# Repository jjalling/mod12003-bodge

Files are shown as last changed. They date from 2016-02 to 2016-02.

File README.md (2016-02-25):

MOD12003 bodge board
====================

During testing, the linear driver on the MOD12003 was shown not to be robust
enough; it lost bias during an abusive "file" test (rapidly shorting/opening
the output by rubbing a wire over a file). This is an updated driver circuit
to be patched into Rev A of MOD12003.

This repository uses submodules. Download with `git clone --recursive`.

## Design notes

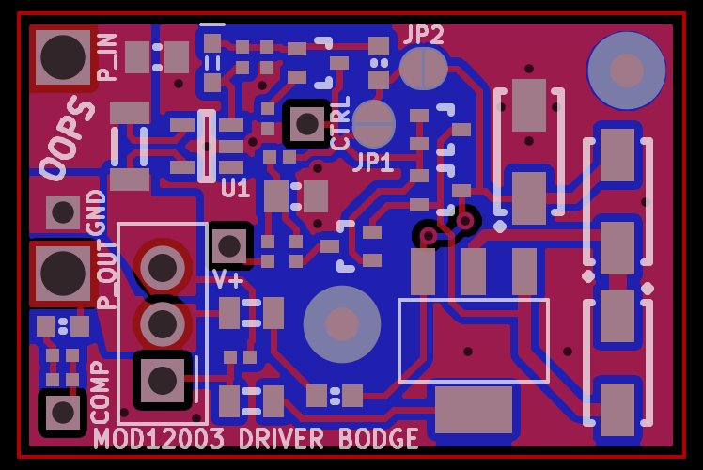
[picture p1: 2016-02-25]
renders/Overview.png

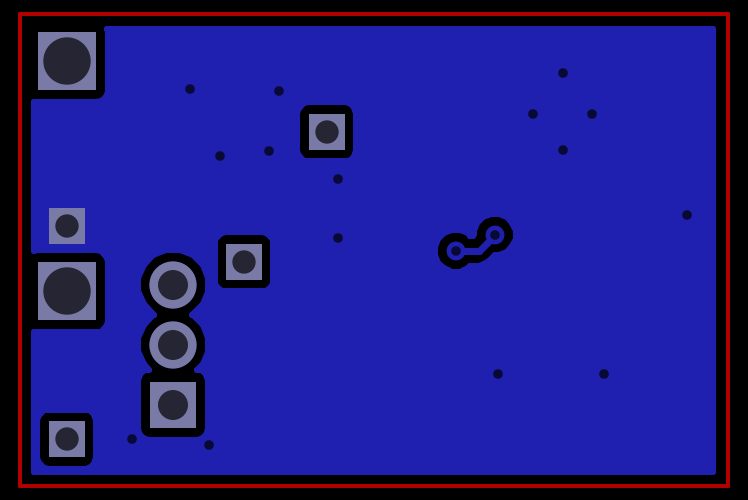
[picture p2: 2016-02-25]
renders/B_Cu.png

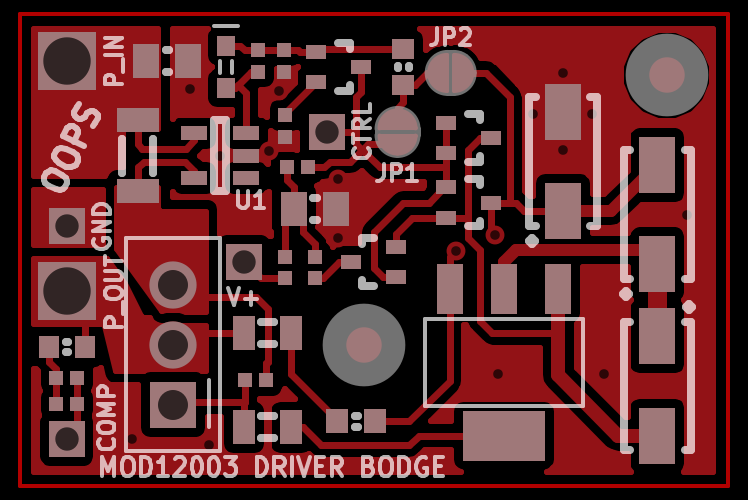
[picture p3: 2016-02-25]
renders/F_Cu.png

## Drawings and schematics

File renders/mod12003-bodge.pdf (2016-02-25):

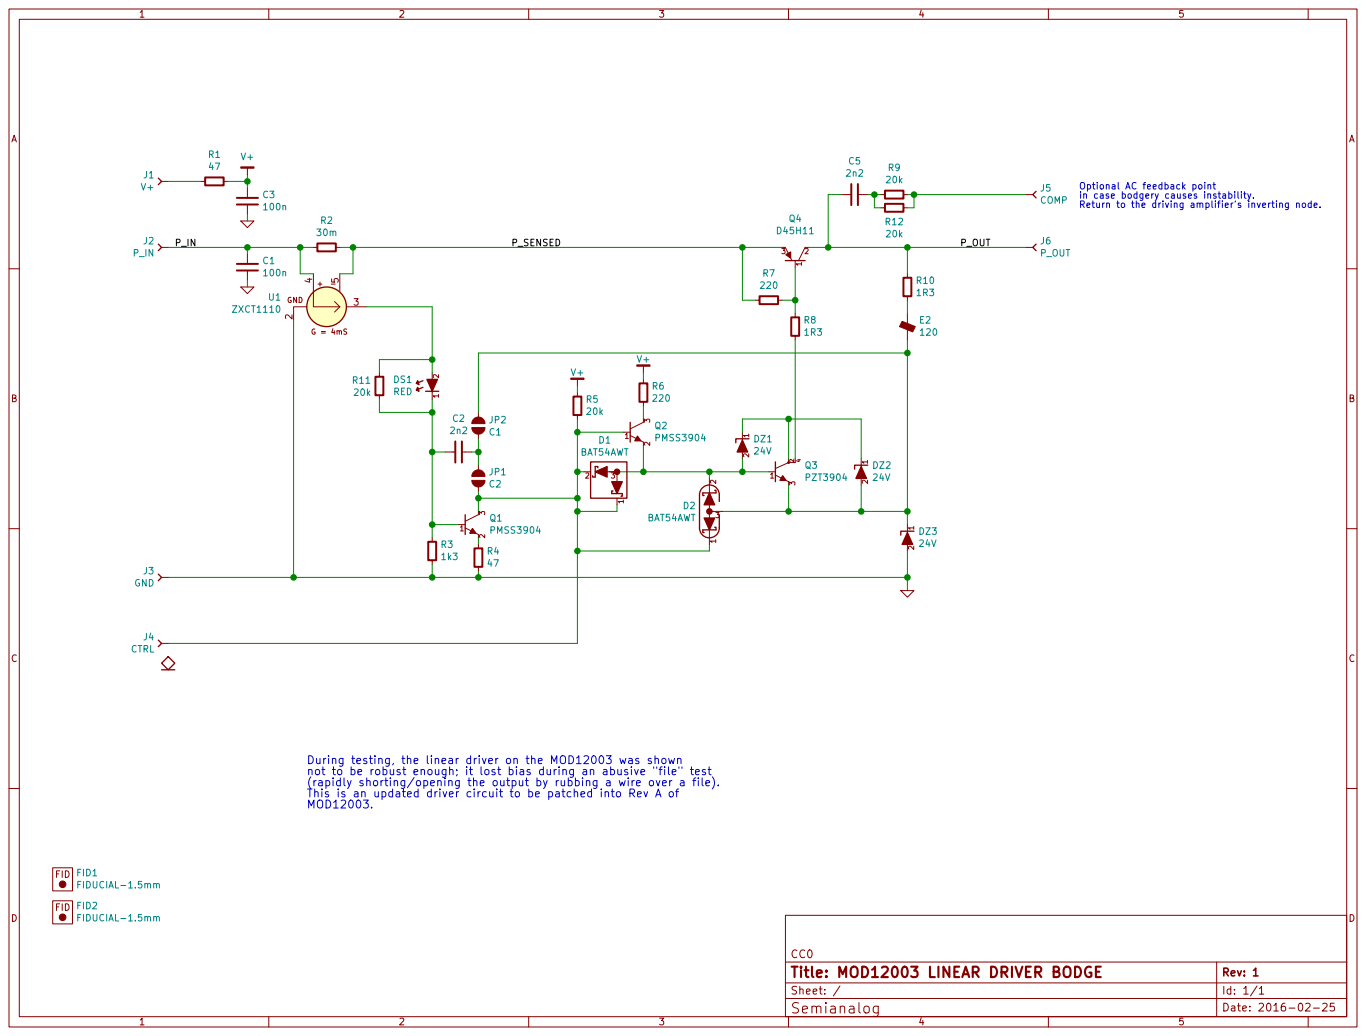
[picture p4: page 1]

in case bodgery causes instability.

Return to the driving amplifier's inverting node. R2

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

Sheet: / CC0
Id: 1/1 Title: MOD12003 LINEAR DRIVER BODGE

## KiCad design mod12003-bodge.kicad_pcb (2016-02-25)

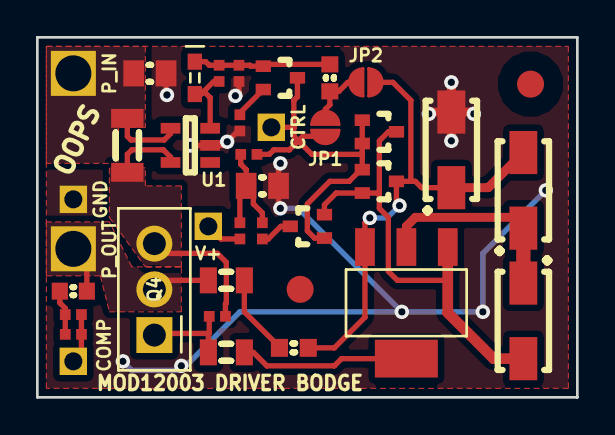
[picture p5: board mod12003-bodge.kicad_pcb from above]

Board: 2 copper layers, 30.0 x 20.0 mm, 38 parts (0 on the bottom side), 20 nets.

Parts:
C1, C3: 100n; CAPC2012X70
C2, C5: 2n2; CAPC1608X55
D1, D2: BAT54AWT; SC-70
DS1: RED; LED-0603
DZ1, DZ2, DZ3: 24V; DIOM5226X203
E2: 120; INDC1608X95
FID1, FID2: FIDUCIAL-1.5mm
J1: V+; CONN-100MIL-F-1x1
J2: P_IN; CONN-100MIL-F-1x1
J3: GND; CONN-100MIL-F-1x1
J4: CTRL; CONN-100MIL-F-1x1
J5: COMP; CONN-100MIL-F-1x1
J6: P_OUT; CONN-100MIL-F-1x1
JP1: C2; JUMPER-SOLDER-SMD
JP2: C1; JUMPER-SOLDER-SMD
Q1, Q2: PMSS3904; SC-70
Q3: PZT3904; SOT-223
Q4: D45H11; TO-220
R1, R4: 47; RESC1005X40
R2: 30m; RESC3216X60
R3: 1k3; RESC1005X40
R5, R9, R11, R12: 20k; RESC1005X40
R6, R7: 220; RESC1005X40
R8, R10: 1R3; RESC2012X50
U1: ZXCT1110; SOT-23-5

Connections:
/P_IN: C1.1, J2.1, R2.2, U1.4
/P_OUT: C5.2, J6.1, Q4.2, R10.1
/P_SENSED: Q4.3, R2.1, R7.2, U1.5
GND: C1.2, C3.2, DZ3.2, J3.1, R3.2, R4.2, U1.2
unnamed: C2.1, JP1.1, JP2.1
unnamed: C2.2, DS1.1, Q1.1, R3.1, R11.1
unnamed: C3.1, R1.1, R5.1, R6.1
unnamed: C5.1, R9.2, R12.2
unnamed: D1.1, D1.2, D2.1, J4.1, JP1.2, Q1.3, Q2.1, R5.2
unnamed: D1.3, D2.2, DZ1.2, Q2.2, Q3.1
unnamed: D2.3, DZ2.2, DZ3.1, E2.2, JP2.2, Q3.3
unnamed: DS1.2, R11.2, U1.3
unnamed: DZ1.1, DZ2.1, Q3.2
unnamed: E2.1, R10.2
unnamed: J1.1, R1.2
unnamed: J5.1, R9.1, R12.1
unnamed: Q1.2, R4.1
unnamed: Q2.3, R6.2
unnamed: Q3.4, R8.2
unnamed: Q4.1, R7.1, R8.1

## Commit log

2016-02-25 Add KiCad files
    [mod12003-bodge-B.Cu.gbl, mod12003-bodge-B.Mask.gbs, mod12003-bodge-B.Paste.gbp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]
2016-02-25 Production version
    [mod12003-bodge-B.Cu.gbl, mod12003-bodge-B.Mask.gbs, mod12003-bodge-B.Paste.gbp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]
